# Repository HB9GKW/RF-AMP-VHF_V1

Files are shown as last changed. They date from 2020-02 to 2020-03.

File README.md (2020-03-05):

# RF-AMP-VHF_V1
2 Meter VHF LDMOS amplifier module:
- 1500W output power at 1dB compression 
- On-Board low-pass filter (5th order chebyshev)
- On-board directional coupler and temperature compensated forward / reflected detector
- Temperature measurement and BIAS stabilization
- RF input detector
- high-power 9:1 TLT

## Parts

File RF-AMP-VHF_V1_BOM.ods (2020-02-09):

Source: | RF-AMP-VHF_V1/RF-AMP-VHF_V1.sch
Date: | Sun 19 Jan 2020 07:01:49 PM CET
Tool: | Eeschema 5.1.5+dfsg1-2~bpo10+1
Generator: | /usr/share/kicad/plugins/bom_csv_grouped_by_value_with_fp.py
Component Count: | 132
Ref | Qnty | Value | Cmp name | Footprint | Description | Distributor
C1, C2, C3, C4, C11, C12, C13, C20, C23, C24, C26, C27, C35, C38, C49, C60, C61, | 17 | 100n | C_Small | Capacitor_SMD:C_0805_2012Metric | Unpolarized capacitor, small symbol | Mouser
C5, | 1 | 220p | C_Small | Capacitor_SMD:C_0805_2012Metric | Unpolarized capacitor, small symbol | Mouser
C6, C7, | 2 | 10u | CP_Small | Capacitor_SMD:CP_Elec_5x5.7 | Polarized capacitor, small symbol | Mouser
C8, C9, | 2 | 1p8 | C_Small | Capacitor_SMD:C_0805_2012Metric | Unpolarized capacitor, small symbol | Mouser
C10, | 1 | 1p8 | C_Small | Capacitor_SMD:C_1210_3225Metric | Unpolarized capacitor, small symbol | Mouser
C14, | 1 | 100n | C_Small | Capacitor_SMD:C_1210_3225Metric | Unpolarized capacitor, small symbol | Mouser
C15, C21, C22, | 3 | 10n | C_Small | Capacitor_SMD:C_1210_3225Metric | Unpolarized capacitor, small symbol | Mouser
C16, C17, C19, | 3 | 1n | C_Small | Capacitor_SMD:C_1210_3225Metric | Unpolarized capacitor, small symbol | Mouser
C18, | 1 | 10p | C_Small | Capacitor_SMD:C_1210_3225Metric | Unpolarized capacitor, small symbol | Mouser
C25, C31, | 2 | 15p | C_Small | Capacitor_SMD:C_2220_5650Metric | Unpolarized capacitor, small symbol | Mouser
C28, C29, C33, C34, C36, C37, | 6 | 1n | C_Small | Capacitor_SMD:C_1812_4532Metric | Unpolarized capacitor, small symbol | Mouser
C30, C32, C39, C40, C41, C42, C43, C44, | 8 | 470p | C_Small | Capacitor_SMD:C_1812_4532Metric | Unpolarized capacitor, small symbol | Mouser
C45, C46, | 2 | 10n | C_Small | Capacitor_SMD:C_1812_4532Metric | Unpolarized capacitor, small symbol | Mouser
C47, C48, | 2 | 100n | C_Small | Capacitor_SMD:C_1812_4532Metric | Unpolarized capacitor, small symbol | Mouser
C50, C51, | 2 | 220u | CP_Small | Capacitor_SMD:CP_Elec_18x22 | Polarized capacitor, small symbol | Mouser | EEV-FK2A221M (https://www.mouser.ch/ProductDetail/Panasonic/EEV-FK2A221M)
C52, C53, C54, C55, | 4 | 1p8 | C_Small | Capacitor_SMD:C_2220_5650Metric | Unpolarized capacitor, small symbol | Mouser
C56, C57, C58, C59, | 4 | 330p | C_Small | Capacitor_SMD:C_0805_2012Metric | Unpolarized capacitor, small symbol | Mouser
C62, | 1 | 22p | C_Small | Capacitor_SMD:C_1210_3225Metric | Unpolarized capacitor, small symbol | Mouser
D1, D5, D6, D7, D8, | 5 | BAT54SW | BAT54SW | Package_TO_SOT_SMD:SOT-323_SC-70 | Dual schottky barrier diode, in series, SOT-323 | Mouser | BAT54SWT1G (https://www.mouser.ch/ProductDetail/ON-Semiconductor/BAT54SWT1G)
D2, D4, | 2 | BZX84C5V1 | BZX84Cxx | Diode_SMD:D_SOT-23_ANK | 300mW Zener Diode, SOT-23 | Mouser | BZX84C5V1LT1G (https://www.mouser.ch/ProductDetail/ON-Semiconductor/BZX84C5V1LT1G)
D3, | 1 | 1N4148W | 1N4148W | Diode_SMD:D_SOD-123 | 75V 0.15A Fast Switching Diode, SOD-123 | Mouser | 1N4148W-E3-18 (https://www.mouser.ch/ProductDetail/Vishay-Semiconductors/1N4148W-E3-18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)
FB1, FB2, FB3, FB4, FB5, | 5 | BLM21BD102 | Ferrite_Bead_Small | Resistor_SMD:R_0805_2012Metric | SMT ferrite bead | Mouser | BLM21BD102SN1D (https://www.mouser.ch/ProductDetail/Murata-Electronics/BLM21BD102SN1D)
L1, | 1 | 820n | L | Inductor_SMD:L_Neosid_Air-Coil_SML_6-10turn_HDM0431A-HDM1031A | Inductor 6 turns hand-wound | Mouser
L2, | 1 | 820n | L | RF-AMP-VHF_V1:L_Neosid_Air-Coil_SML_6-10turn_HDM0431A-HDM1031A | Inductor 6 turns hand-wound | Mouser
L3, L4, L5, L6, L7, | 5 | L | L | RF-AMP-VHF_V1:Air_Coil_1 | Inductor hand-wound | Mouser
L8, L9, | 2 | 22n | L | Inductor_SMD:L_Neosid_Air-Coil_SML_3turn_HDM0331A | Inductor | Mouser
Q1, | 1 | BC857 | BC857 | Package_TO_SOT_SMD:SOT-23 | 0.1A Ic, 45V Vce, PNP Transistor, SOT-23 | Mouser
Q2, | 1 | BLF189XRA | LDMOS | RF-AMP-VHF_V1:SOT-539 |  | Mouser
Q3, | 1 | BC847 | BC847 | Package_TO_SOT_SMD:SOT-23 | 0.1A Ic, 45V Vce, NPN Transistor, SOT-23 | Mouser
R1, R19, R21, R26, R28, | 5 | 4k7 | R | Resistor_SMD:R_0805_2012Metric | Resistor | Mouser
R2, | 1 | 470 | R | Resistor_SMD:R_0805_2012Metric | Resistor | Mouser
R3, | 1 | 10 | R | Resistor_SMD:R_4020_10251Metric | Resistor | Mouser
R4, R6, | 2 | 10 | R | Resistor_SMD:R_2010_5025Metric | Resistor | Mouser
R5, | 1 | 50 | R | Resistor_SMD:R_2010_5025Metric | Resistor | Mouser
R7, R8, R9, | 3 | 47k | R | Resistor_SMD:R_0805_2012Metric | Resistor | Mouser
R10, R12, R14, R16, | 4 | 100k | R | Resistor_SMD:R_0805_2012Metric | Resistor | Mouser
R11, | 1 | 490k | R | Resistor_SMD:R_0805_2012Metric | Resistor | Mouser
R13, R15, | 2 | 220k | R | Resistor_SMD:R_0805_2012Metric | Resistor | Mouser
R17, | 1 | 330 | R | Resistor_SMD:R_0805_2012Metric | Resistor | Mouser
R18, R29, | 2 | 51 | R | Resistor_SMD:R_0805_2012Metric | Resistor | Mouser
R20, R23, R24, R27, | 4 | 100 | R | Resistor_SMD:R_0805_2012Metric | Resistor | Mouser
R22, R25, | 2 | 68 | R | Resistor_SMD:R_0805_2012Metric | Resistor | Mouser
R30, R32, | 2 | 100 | R_EP | Package_TO_SOT_SMD:TO-263-2 | Resistor | Mouser
R31, | 1 | 68 | R_EP | Package_TO_SOT_SMD:TO-263-2 | Resistor | Mouser
RV1, | 1 | 20k | R_POT | Potentiometer_SMD:Potentiometer_Bourns_3269W_Vertical | Potentiometer | Mouser
TL1, TL2, | 2 | RG316 | TL |  | Coaxial cable RG316 17cm 50R | Mouser
TL3, TL4, | 2 | RG316_12 | TL |  | Coaxial cable RG316 10cm 12R | Mouser
TL5, TL6, | 2 | TC-12 | TL |  | Coaxial cable TC-12 10cm 12R | Mouser
TL7, TL8, | 2 | RG141 | TL |  | Coaxial cable RG316 17cm 50R | Mouser
U1, | 1 | L78L05_SOT89 | L78L05_SOT89 | Package_TO_SOT_SMD:SOT-89-3 | Positive 100mA 30V Linear Regulator, Fixed Output 5V, SOT-89 | Mouser | L78L05ABUTR (https://www.mouser.ch/ProductDetail/STMicroelectronics/L78L05ABUTR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)
U2, | 1 | L79L05_SOT89 | L79L05_SOT89 | Package_TO_SOT_SMD:SOT-89-3 | Negative 100mA -30V Linear Regulator, Fixed Output -5V, SOT-89 | Mouser | L79L05ABUTR (https://www.mouser.ch/ProductDetail/STMicroelectronics/L79L05ABUTR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)
U3, | 1 | LM7332 | LM7332 | Package_SO:SOIC-8_3.9x4.9mm_P1.27mm | Dual Rail-to-Rail Input and Output 30-V, Wide Voltage Range, High Output, Operational Amplifier, SOIC-8/SSOP-8 | Mouser | LM7332MAX/NOPB (https://www.mouser.ch/ProductDetail/Texas-Instruments/LM7332MAX-NOPB)
U4, | 1 | TMP36GT9 | TMP36xS | Package_TO_SOT_THT:TO-92_Inline_W4.0mm_Horizontal_FlatSideDown | Low Voltage Temperature Sensor, SOIC-8 | Mouser | TMP36GT9 (https://www.mouser.ch/ProductDetail/Analog-Devices/TMP36GT9?qs=sGAEpiMZZMucenltShoSnoiUfjKGVRv2bPXndGQRHgA%3D)

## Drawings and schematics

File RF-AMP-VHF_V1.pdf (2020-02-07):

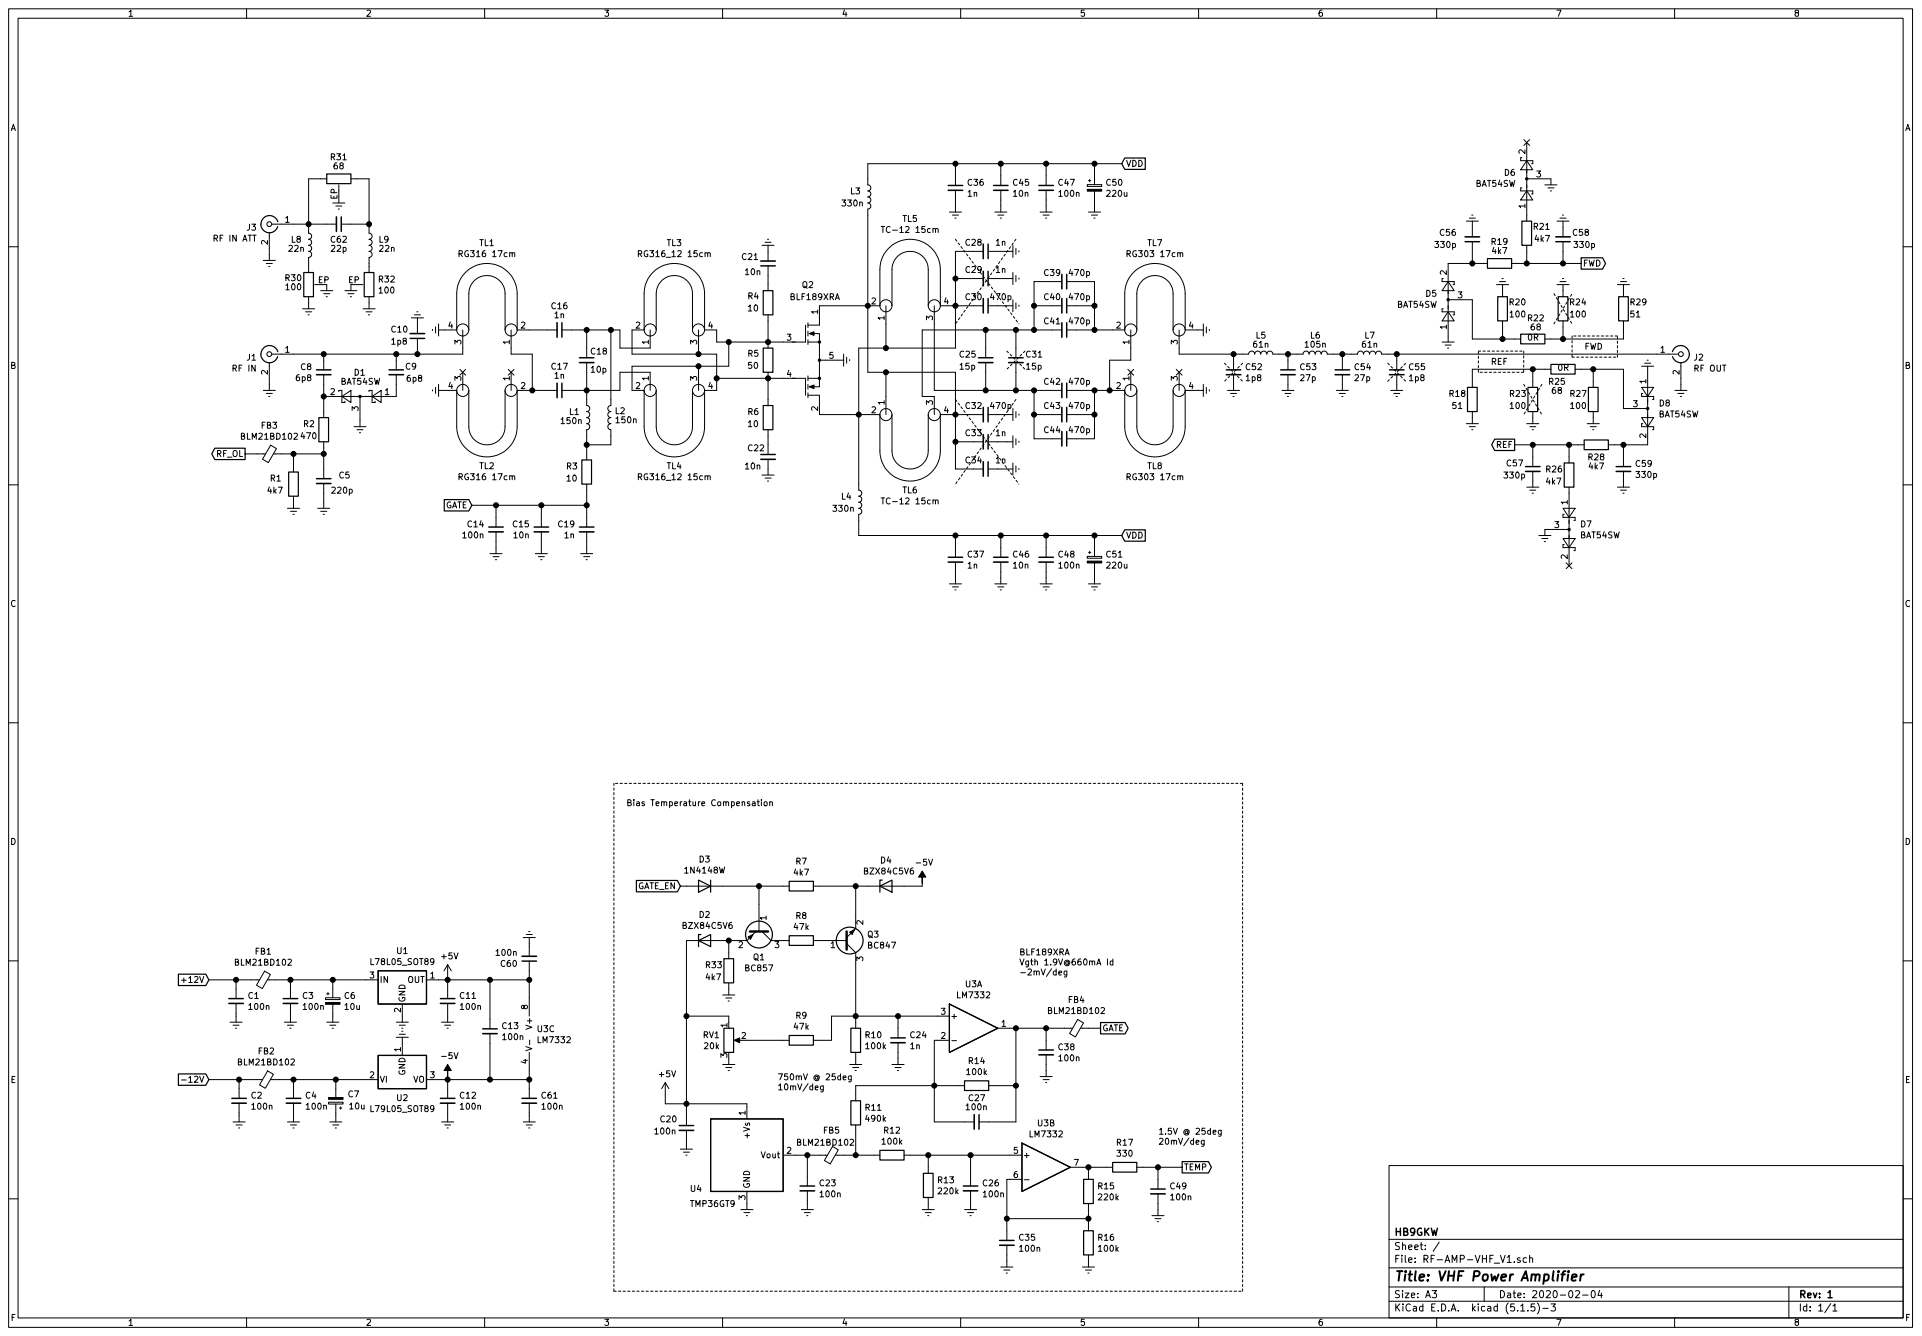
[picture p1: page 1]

File: RF-AMP-VHF_V1.sch Sheet: / HB9GKW

Id: 1/1 Title: VHF Power Amplifier

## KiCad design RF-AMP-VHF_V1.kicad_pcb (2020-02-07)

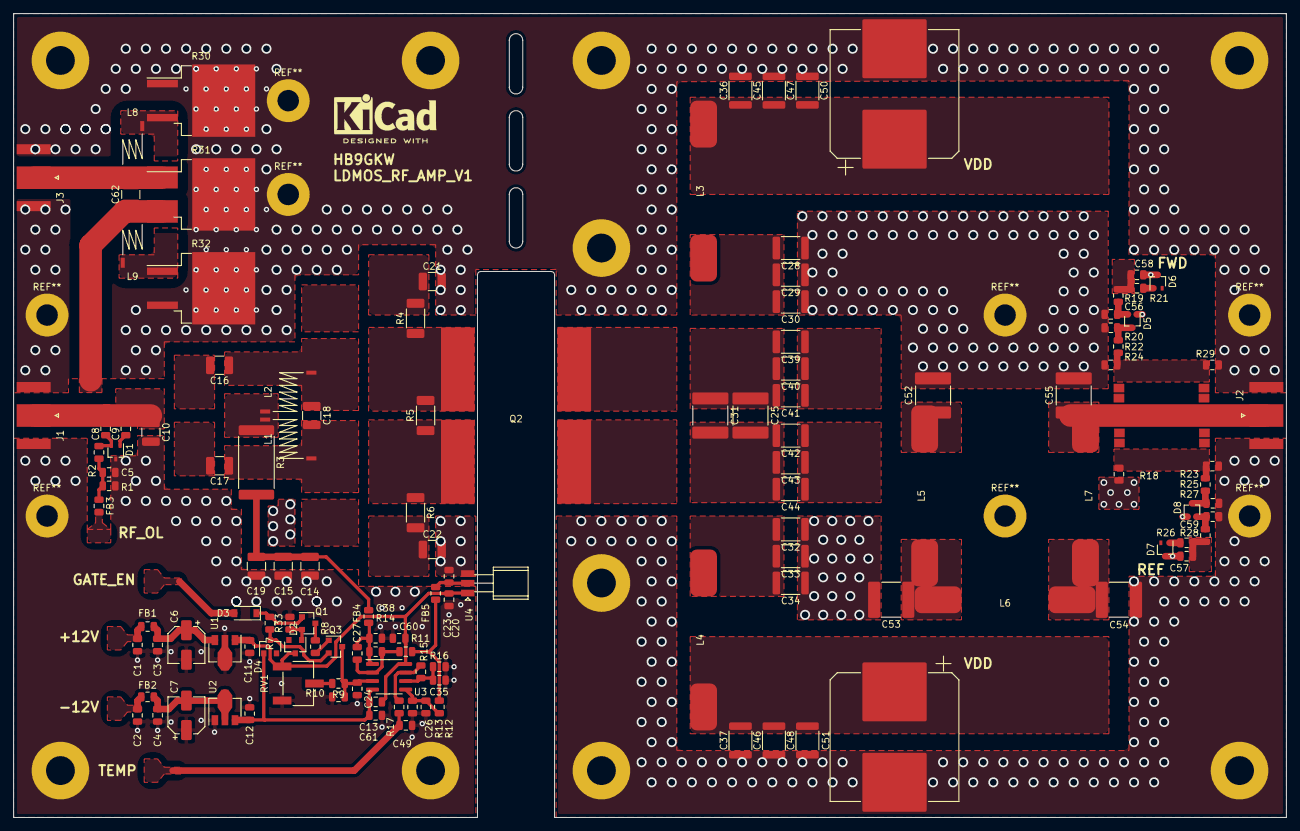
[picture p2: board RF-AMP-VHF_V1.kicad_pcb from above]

Board: 2 copper layers, 190.0 x 120.0 mm, 128 parts (0 on the bottom side), 59 nets.

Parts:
C1, C2, C3, C4, C11, C12, C13, C20, C23, C26, C27, C35, C38, C49, C60, C61: 100n; C_0805_2012Metric
C5: 220p; C_0805_2012Metric
C6, C7: 10u; CP_Elec_5x5.7
C8, C9: 6p8; C_0805_2012Metric
C10: 1p8; C_1210_3225Metric
C14: 100n; C_1210_3225Metric
C15, C21, C22: 10n; C_1210_3225Metric
C16, C17, C19: 1n; C_1210_3225Metric
C18: 10p; C_1210_3225Metric
C24: 1n; C_0805_2012Metric
C25, C31: 15p; C_2220_5650Metric
C28, C29, C33, C34, C36, C37: 1n; C_1812_4532Metric
C30, C32, C39, C40, C41, C42, C43, C44: 470p; C_1812_4532Metric
C45, C46: 10n; C_1812_4532Metric
C47, C48: 100n; C_1812_4532Metric
C50, C51: 220u; CP_Elec_18x22
C52, C55: 1p8; C_2220_5650Metric
C53, C54: 27p; C_2220_5650Metric
C56, C57, C58, C59: 330p; C_0805_2012Metric
C62: 22p; C_1210_3225Metric
D1, D5, D6, D7, D8: BAT54SW; SOT-323_SC-70
D2, D4: BZX84C5V6; D_SOT-23_ANK
D3: 1N4148W; D_SOD-123
FB1, FB2, FB3, FB4, FB5: BLM21BD102; R_0805_2012Metric
J1: RF IN; SMA_Amphenol_132289_EdgeMount
J2: RF OUT; SMA_Amphenol_132289_EdgeMount
J3: RF IN ATT; SMA_Amphenol_132289_EdgeMount
L1, L2: 150n; L_Neosid_Air-Coil_SML_6-10turn_HDM0431A-HDM1031A
L3, L4: 330n; Air_Coil_1
L5, L7: 61n; Air_Coil_1
L6: 105n; Air_Coil_1
L8, L9: 22n; L_Neosid_Air-Coil_SML_3turn_HDM0331A
Q1: BC857; SOT-23
Q2: BLF189XRA; SOT-539
Q3: BC847; SOT-23
R1, R7, R19, R21, R26, R28, R33: 4k7; R_0805_2012Metric
R2: 470; R_0805_2012Metric
R3: 10; R_4020_10251Metric
R4, R6: 10; R_2010_5025Metric
R5: 50; R_2010_5025Metric
R8, R9: 47k; R_0805_2012Metric
R10, R12, R14, R16: 100k; R_0805_2012Metric
R11: 490k; R_0805_2012Metric
R13, R15: 220k; R_0805_2012Metric
R17: 330; R_0805_2012Metric
R18, R29: 51; R_0805_2012Metric
R20, R23, R24, R27: 100; R_0805_2012Metric
R22, R25: 68; R_0805_2012Metric
R30, R32: 100; TO-263-2
R31: 68; TO-263-2
RV1: 20k; Potentiometer_Bourns_3269W_Vertical
U1: L78L05_SOT89; SOT-89-3
U2: L79L05_SOT89; SOT-89-3
U3: LM7332; SOIC-8_3.9x4.9mm_P1.27mm
U4: TMP36GT9; TO-92_Inline_W4.0mm_Horizontal_FlatSideDown

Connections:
+5V: C11.1, C13.1, C20.1, C60.1, D2.1, RV1.1, U1.1, U3.8, U4.1
+12V: C1.1, FB1.2
-5V: C12.1, C13.2, C61.1, D4.2, U2.3, U3.4
-12V: C2.1, FB2.2
Earth: C1.2, C2.2, C3.2, C4.2, C5.2, C6.2, C7.1, C10.2, C11.2, C12.2, C14.2, C15.2, C19.2, C20.2, C21.2, C22.2, C23.2, C24.2, C26.2, C28.1, C29.1, C30.1, C32.1, C33.1, C34.1, C35.2, C36.2, C37.2, C38.2, C45.2, C46.2, C47.2, C48.2, C49.2, C50.2, C51.2, C52.2, C53.2, C54.2, C55.2, C56.2, C57.2, C58.2, C59.2, C60.2, C61.2, D1.3, D5.1, D6.3, D7.3, D8.1, J1.2, J2.2, J3.2, Q2.5, R1.2, R10.2, R13.2, R16.2, R18.2, R20.2, R23.2, R24.2, R27.2, R29.2, R30.1, R30.2, R31.2, R32.2, R32.3, R33.2, RV1.3, U1.2, U2.1, U4.3
FWD: C58.1, R19.2, R21.1
GATE: C14.1, C15.1, C19.1, FB4.1, R3.2
unnamed: C3.1, C6.1, FB1.1, U1.3
unnamed: C4.1, C7.2, FB2.1, U2.2
unnamed: C5.1, FB3.1, R1.1, R2.2
unnamed: C8.2, D1.2, R2.1
unnamed: C9.2, D1.1
unnamed: C8.1, C9.1, C10.1, J1.1
unnamed: C16.1, C18.1, L2.2
unnamed: C17.1, C18.2, L1.1
unnamed: C21.1, R4.2
unnamed: C22.1, R6.2
unnamed: C23.1, FB5.1, U4.2
unnamed: C24.1, Q3.3, R9.1, R10.1, U3.3
unnamed: C25.1, C31.1, C39.2, C40.2, C41.2
unnamed: C25.2, C31.2, C42.2, C43.2, C44.2
unnamed: C26.1, R12.1, R13.1, U3.5
unnamed: C27.1, C38.1, FB4.2, R14.1, U3.1
unnamed: C27.2, R11.1, R14.2, U3.2
unnamed: C28.2, C29.2, C30.2, L4.1, Q2.2
unnamed: C32.2, C33.2, C34.2, L3.2, Q2.1
unnamed: C35.1, R15.2, R16.1, U3.6
unnamed: C39.1, C40.1, C41.1
unnamed: C42.1, C43.1, C44.1
unnamed: C52.1, L5.1
unnamed: C53.1, L5.2, L6.1
unnamed: C54.1, L6.2, L7.1
unnamed: C55.1, J2.1, L7.2
unnamed: C56.1, D5.2, R19.1
unnamed: C59.1, D8.2, R28.1
unnamed: C62.1, L9.1, R31.3
unnamed: C62.2, J3.1, L8.1, R31.1
unnamed: D2.2, Q1.2, R33.1
unnamed: D3.1, Q1.1, R7.2
unnamed: D4.1, Q3.2, R7.1
unnamed: D5.3, R20.1, R22.2
unnamed: D6.1, R21.2
unnamed: D7.1, R26.2
unnamed: D8.3, R25.1, R27.1
unnamed: FB5.2, R11.2, R12.2
unnamed: L1.2, L2.1, R3.1
unnamed: L8.2, R30.3
unnamed: L9.2, R32.1
unnamed: Q1.3, R8.2
unnamed: Q2.3, R4.1, R5.2
unnamed: Q2.4, R5.1, R6.1
unnamed: Q3.1, R8.1
unnamed: R9.2, RV1.2
unnamed: R15.1, R17.2, U3.7
unnamed: R18.1, R23.1, R25.2
unnamed: R22.1, R24.1, R29.1
REF: C57.1, R26.1, R28.2
TEMP: C49.1, R17.1
VDD: C36.1, C37.1, C45.1, C46.1, C47.1, C48.1, C50.1, C51.1, L3.1, L4.2

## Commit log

2020-01-13 changing gerber format
    [RF-AMP-VHF_V1-B_Cu.gbr, RF-AMP-VHF_V1-B_Mask.gbr, RF-AMP-VHF_V1-Edge_Cuts.gbr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]
2020-01-14 Review 1
    [RF-AMP-VHF_V1-B_Cu.gbr, RF-AMP-VHF_V1-B_Mask.gbr, RF-AMP-VHF_V1-Edge_Cuts.gbr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]
2020-01-18 prototype release
    [RF-AMP-VHF_V1-B_Cu.gbr, RF-AMP-VHF_V1-B_Mask.gbr, RF-AMP-VHF_V1-Edge_Cuts.gbr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]
2020-01-19 added BOM
    [RF-AMP-VHF_V1_BOM.ods]
2020-02-04 bug fixes
    [RF-AMP-VHF_V1-B_Cu.gbr, RF-AMP-VHF_V1-B_Mask.gbr, RF-AMP-VHF_V1-Edge_Cuts.gbr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]
2020-02-05 schematic update
    [RF-AMP-VHF_V1.sch]
2020-02-07 prototype improvements
    [RF-AMP-VHF_V1-B_Cu.gbr, RF-AMP-VHF_V1-B_Mask.gbr, RF-AMP-VHF_V1-Edge_Cuts.gbr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]
